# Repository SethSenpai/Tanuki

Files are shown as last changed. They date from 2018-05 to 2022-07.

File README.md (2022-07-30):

# Tanuki 40% keyboard
### The trash panda 40%

Tanuki

#### What is the Tanuki?
The Tanuki is a 40% keyboard that uses a split spacebar design to comfortably switch between layers. The design goal for the Tanuki was to make a staggered 40% keyboard out of materials I had lying around in my workshop.
This is also where it gets its name. A Tanuki or [Japanese raccoon dog](https://en.wikipedia.org/wiki/Japanese_raccoon_dog) is also known as a trash panda on the internet, which I felt was a fitting name for something build out of leftover materials.

#### Why open source?
The reason I am not doing a group buy or anything else of the sort is because I want people to experiment. To try different things with a keyboard that is not going to ruin your bank account if you get it wrong the first time.
I feel that running a group buy or outright producing this keyboard will take away the experimental nature of the project. I want people to take what I designed and mold it into something that is theirs. To use this more as a platform of departure rather than a guide to follow. Ok, I will stop rambling about design philosophy now.

You are of course more than welcome to run your own group buy!
**If you intend to use this design for commercial use, please go right ahead!**

#### Features
+ A staggered design.
+ Extremely small bezel.
+ Interactive RGB underglow that shows what layer you're on.
+ Buttons to turn off or reconfigure your underglow.
+ The ability to modify and adapt the keyboard to your wildest dreams! (and perhaps learn new skills doing so!)

#### How do I use the Tanuki?
The Tanuki works by having a split spacebar design. Holding either side of the spacebar will shift the keyboard to a different layer giving you access to the characters on that layer. 
Please note that while playing video games you should switch to the game layer. Some games to not handle the spacebar hold interaction well and will eat your inputs. (not good when playing your high adrenaline games)
Switching to the game layer will remove the hold function from the spacebar, fixing the problem.

#### Where is %this_key% on the keyboard?
The Tanuki has 3 layers, if the key you want is not on any of these layers you will have to dive into the firmware and put it somewhere you like!

**Base layer:**

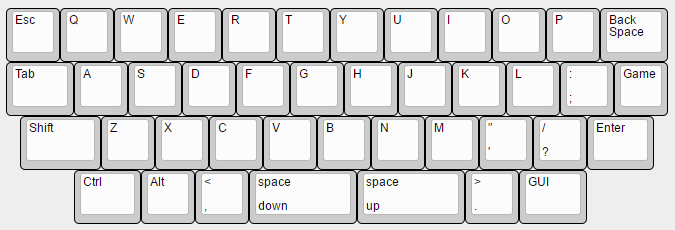
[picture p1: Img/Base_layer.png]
base


**Up layer:**

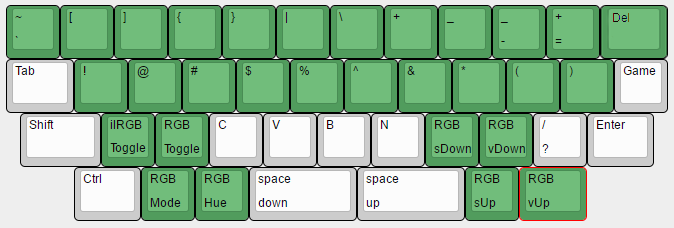
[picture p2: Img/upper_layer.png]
up


**Down layer:**

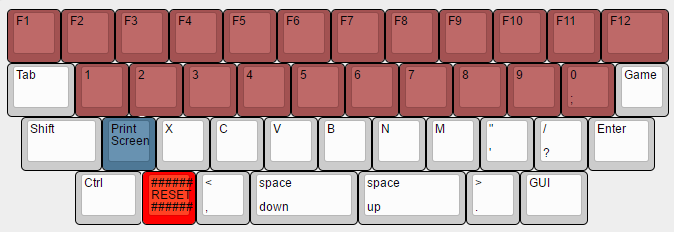
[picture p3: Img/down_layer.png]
down


**Game layer: (sort of a bad name I know more like arrow layer ah well)**

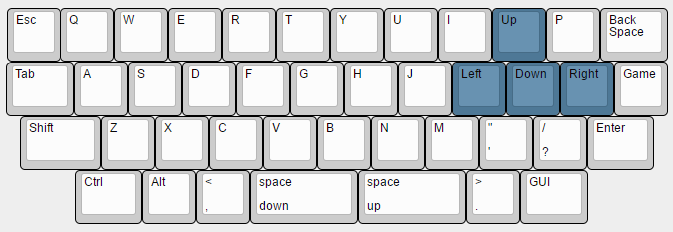
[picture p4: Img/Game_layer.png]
game


#### I'm sold, where do I go from here?
Visit the `Assembly and Parts` folder to get an idea of how to construct a Tanuki. Otherwise start by making a case by going to the `Case` folder. From there you can decide to handwire your Tanuki or have a pcb made. After that comes assembly and firmware! 

#### More pictures please?
glam2
glam3
glam4

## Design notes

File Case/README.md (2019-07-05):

# Tanuki 40% keyboard
### Case files

These are the case files for the Tanuki. There is a choice between 3d printing and lasercutting a sandwich case. Both have their own advantages and disadvantages. Notably for 3d printing is the time needed for printing the parts and the time investment to make it pretty afterwards. For lasercutting its the amount of paintwork that needs to be done and the relative annoying way of assembly.

### 3D Printing
The 3d printing files are split up into 5 files. Don't freak out most of them can be ignored based on your preferences and 3d printer. The full keyboard case doesn't fit on my Anet A6 and when I look around at the bed sizes for most 3d printers it likely won't fit on yours either. This is why the keyboard is split into 2 pieces.

*In case you have a big 3d printer*
+ TanukiCase.stl
+ TanukiCase_nologo.stl

*In case you have a 3d printer with a "average" size printbed*
+ TanukiCase_left.stl
+ TanukiCase_right.stl
+ TanukiCase_right_nologo.stl

The ..._nologo files are there because they have no indented logo on their front face. With 3d printed parts being more porous than smooth acrylic it is near impossible to scrape the paint off the front without paint streaks. I ended up filling it in with a very thin needle and the end result is well... ok enough? It is nowhere perfect so I decided to include files without the logo so you have a choice. Maybe a sticker is a better way to go...

*Print settings*

These vary from printer to printer, don't expect the first attempt to come out perfect.

+ layer height: 0.2mm
+ wall thickness: 1.2mm
+ infill density: 30%
+ infill pattern: lines
+ no support needed

You may need to rotate the model so the front of the case is laying down on the bed of the printer.

*Print aftercare*

Make sure to sand the inside of the mating surfaces of your print before attempting to glue it together. Glueing the parts together works really well with some low viscosity CA glue.

*What about the bottom of the case?*

Currently I just mount a lasercut 3mm clear acrylic part on the bottom with some 3mm bolts. However in the future I might design some nice 3d printed part that lets the light through nicely.

### Lasercutting
The Tanuki is designed to be laser cut out of 3mm acrylic but you are welcome to experiment. Please keep in mind the height needed for the components.
+ BLACK is a raster engraving.
+ BLUE should be the first lines to get cut.
+ CYAN should be the second lines to get cut.

If your local lasercut shop uses the colours differently please adjust them according to their specifications.

The strange circles and rectangles are there to be used as standoffs or as a way to hold the micro controller in place in case you're doing a handwired build.

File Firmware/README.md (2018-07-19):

# Tanuki 40% keyboard
### [Firmware files](https://github.com/qmk/qmk_firmware/tree/master/keyboards/tanuki)

#### Why are these files here?
The firmware files are also hosted over at [QMK](https://github.com/qmk/qmk_firmware/tree/master/keyboards/tanuki) and should be used to compile the firmware in a way that you like. These files are posted here to consolidate the files in one place and allow people to compile using older versions of QMK.

#### What do I do with this?
If this is your first time compiling keyboard firmware you might want to check out the [QMK guide](https://docs.qmk.fm/) or if you made no changes just [flash the .hex file to your pro micro](https://docs.qmk.fm/#/flashing).

#### Some notes on this firmware
This firmware release is for the PCB version only.

40% keyboard designed by Seth-Senpai. This repo is meant for the pcb version of the Tanuki. If you made any modifications to the board please make sure that the firmware reflects these changes.

If you decide to handwire a Tanuki just make sure to change the files correctly. If you're lost you can check out the [QMK hand wiring guide](https://docs.qmk.fm/#/hand_wire). The matrix is displayed below.

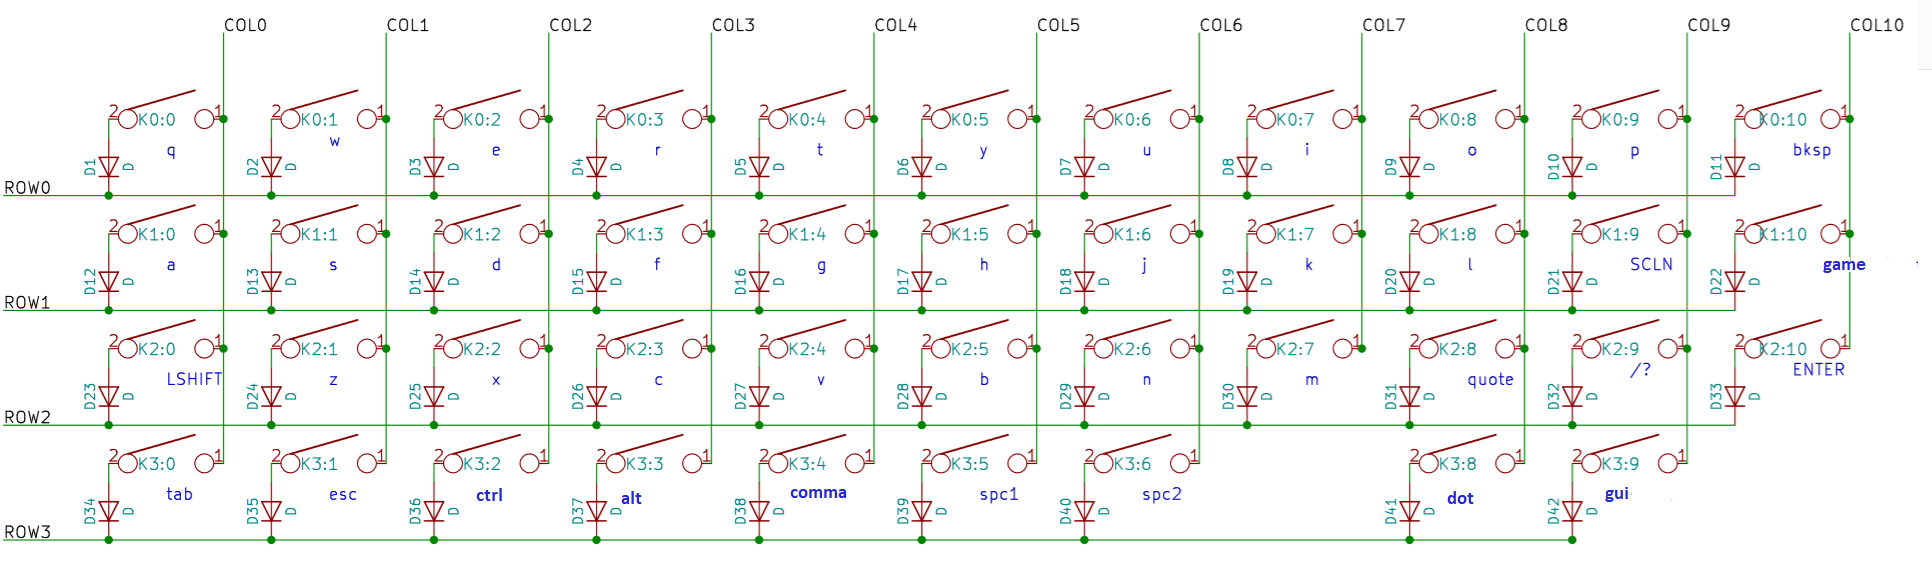
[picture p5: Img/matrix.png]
matrix


The pcb version uses a Pro Micro (atmel 32u4 based) controller.

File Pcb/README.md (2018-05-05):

# Tanuki 40% keyboard
### PCB files

#### What do I do with this?
+ If you just want to have a pcb made. Use the `Tanuki-gerber.zip` file and upload this to your pcb manufacturer of choice.
+ The files in the `Tanuki-gerber-files` folder mirror the files in the zip and this folder can be used to check if all the files that your manufacturer needs are there.
+ Otherwise modifications or new gerber files can be made by using the files found in the `Kicad files` folder.

Special thanks to [StormPegy](https://github.com/Stormpegy) for making the pcb.

#### Picture of a manufactured pcb
tanuki pcb

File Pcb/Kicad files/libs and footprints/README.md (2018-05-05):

# Tanuki 40% keyboard
### libraries and footprints

All rights to the respective owners of these libraries.

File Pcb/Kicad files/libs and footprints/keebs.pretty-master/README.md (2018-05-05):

# keebs.pretty

A KiCAD library for hybrid Cherry MX and Alps footprints that supports PCB mounted Cherry stabilizers. This is a revision of files found in [kiibohd/pcb](https://github.com/kiibohd/pcb) and [stormbard/Keyboard.pretty](https://github.com/stormbard/Keyboard.pretty)

Checkout [this tutorial](http://www.accelerated-designs.com/help/KiCad_Library.html)
if you are unfamiliar with importing KiCAD libraries.

If you come across any issues please don't hesitate to report them. Contributions are encouraged!

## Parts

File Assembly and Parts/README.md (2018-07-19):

# Tanuki 40% keyboard
### Materials and Assembly

These are not instructions. Keep in mind that you can change anything you like if you think it will work!

#### Part list pcb
|quantity  | description |
|---|---|
| x42 | diode smd: SOD-123 / SOD-80 (1N4148W / LL4148) or diode tht: DO-35 (1N4148 or similar) |
| x42 | MX style switches |
| x1 | resistor: 0603 500ohm |
| x1 | usb port: molex 54819-0519 |
| x1 | controller: arduino pro micro + headers |
| x5 | underglow led: WS2812B, this can also be a neopixel strip with 5 leds. |
| x1 | reset button: 3x6x2.5mm push button |
| x2 | stabilizer: costar style 2 unit (optional)|
| x1 | usb pigtail: cheap generic microusb cable to cut |

#### Part list case
|quantity  | description |
|---|---|
| x6 | 3M hexagonal nut. 2.4mm height. |
| x6 | 3M bolt. either 16 or 18 mm depending on the thickness of the board. |

#### Keycaps
I recommend using a DSA profile keycap but you can do anything you like. Freestyle man!

|quantity  | description |
|---|---|
| x34 | 1U keycap |
| x2 | 2U keycap |
| x5 | 1.25U keycap |
| x1 | 1.5U keycap |

#### Case parts preparation before assembly

If you want you can paint the upper parts of the keyboard so the underglow only shines through the bottom plate. When picking your spray-paint make sure that the propellant doesn't eat away at the plastic. Some of the propellants can be corrosive.

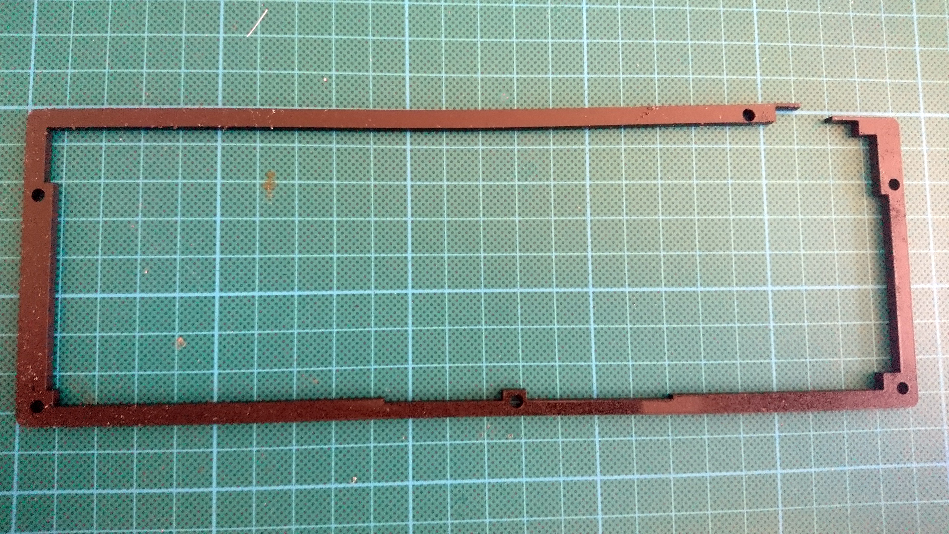
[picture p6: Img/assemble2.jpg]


The engraving on the front of the plate can be painted after by hand or filled by paint and then scraped off and cleaned off later with some isopropanol.

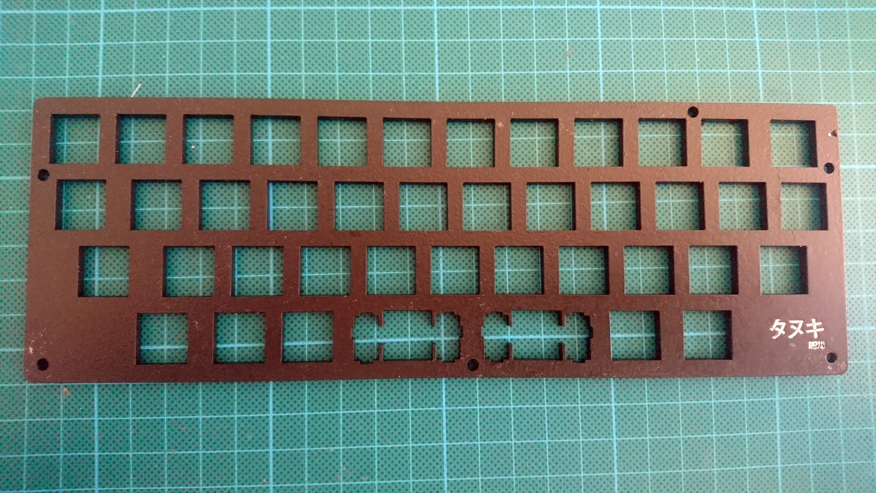
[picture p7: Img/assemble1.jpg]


If you want you can countersink the holes in top of the plate so the screws will fit on nice and flush later on.

The backplate can be sanded to increase the diffusion of the underglow through the side of the backplate. This makes the glow effect more spread and less like a flashlight.
In order to fit the backplate to the rest of the keyboard you should install some 3mm nuts in the slots on the backplate. You can glue them in place using superglue or epoxy.

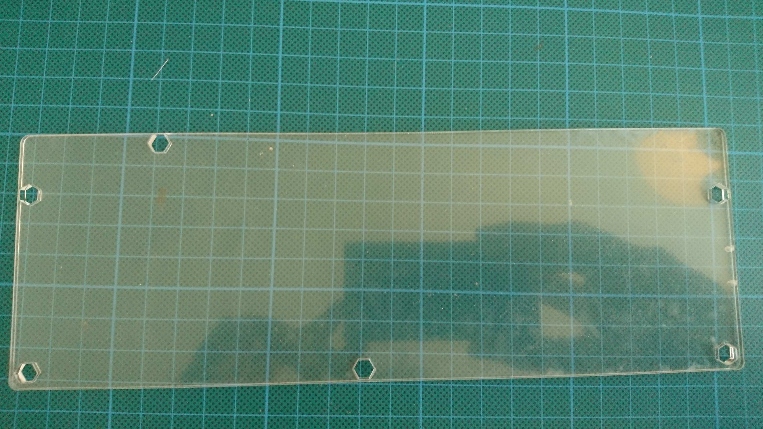
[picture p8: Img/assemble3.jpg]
sanding


When you're done it should look something like this: (except it won't be assembled yet)

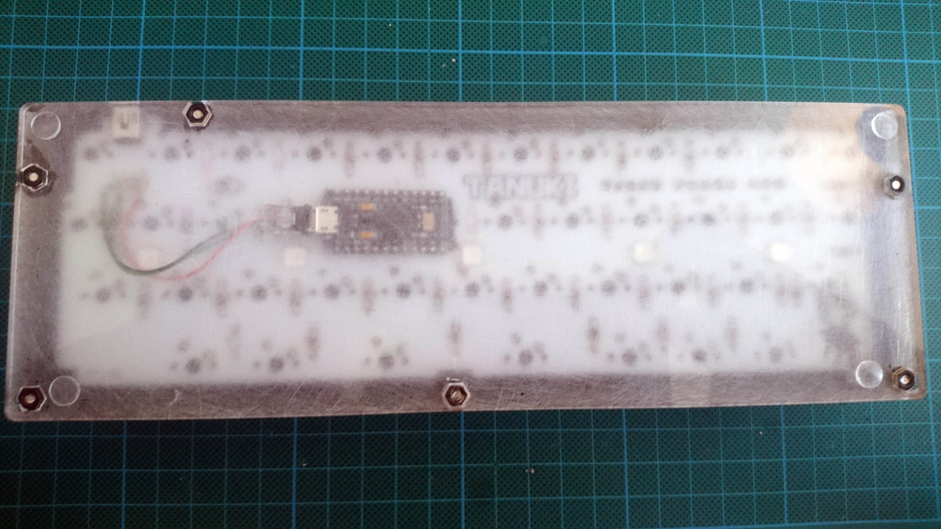
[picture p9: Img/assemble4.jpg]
assembled


#### Hand wiring

If you decide to handwire a Tanuki just make sure to change the files correctly. If you're lost you can check out the [QMK hand wiring guide](https://docs.qmk.fm/#/hand_wire). The matrix is displayed below.

matrix

#### PCB assembly

First part to solder to your pcb is the reset switch (if you have one) and the resistor for the led data line. ([this is not needed but **highly** recommended,](https://electronics.stackexchange.com/questions/102050/what-is-the-purpose-of-adding-a-300-ohm-to-500-ohm-resistor-on-the-ws2812b-neopi) in that case just bridge the pads).

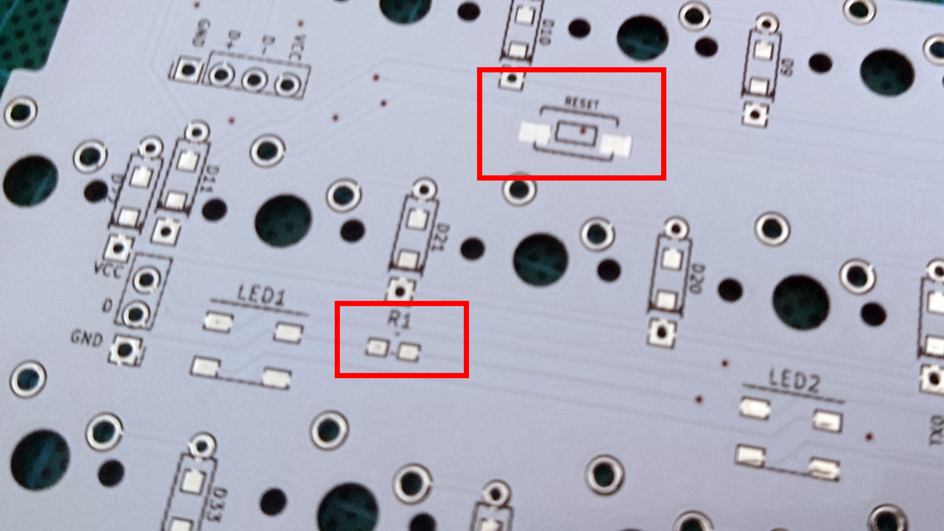
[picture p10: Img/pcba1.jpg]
ass1


The next step is to put all the diodes on the pcb. Make sure that the cathode (generally indicated by a mark on the diode) is pointing towards the square pad on the pcb.
If you're using through hole diodes it might be a good idea to put some diodes on the other side of the pcb. This makes sure that there is a nice spacer between the plate and the pcb and keeps the switches in place nicely.

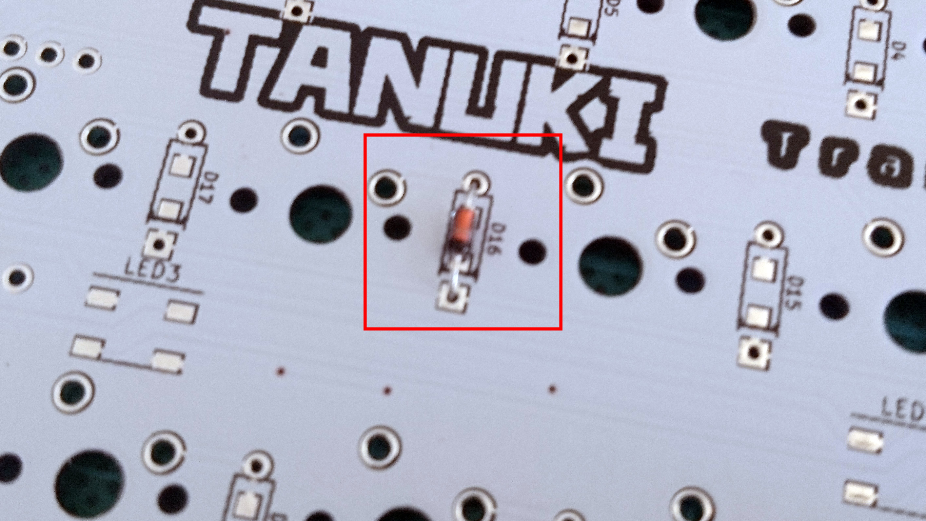
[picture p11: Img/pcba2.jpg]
ass2


Following this it is time to mount the leds on the pcb. When using the smd WS2812B leds make sure that the indent on one of the corners (the red circle in the picture) is pointing to the bottom right of the pcb.
Also keep in mind that the WS2812B leds are pretty heat sensitive so don't cook them!
If you want to hook up a neopixel strip just attach the wires to the appropriate breakout left of the first led.

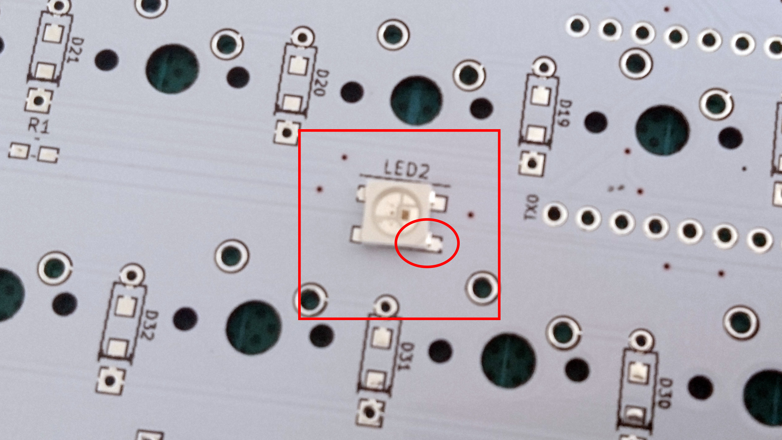
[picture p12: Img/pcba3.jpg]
ass3


Solder the usb chassis to the board. Make sure it is nice and straight.

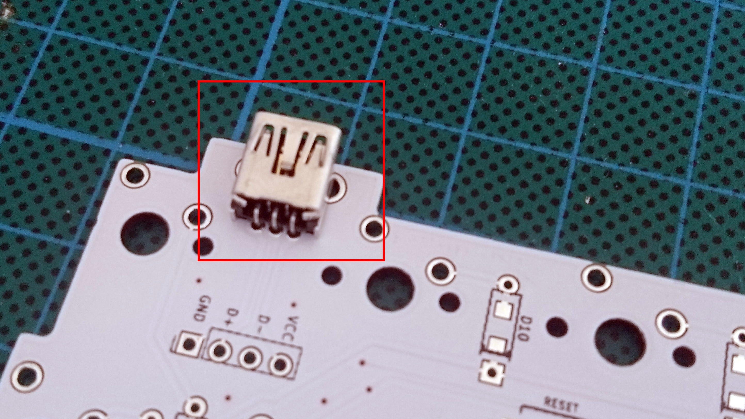
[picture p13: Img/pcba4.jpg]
ass4


Next are the headers for the pro micro. If you want to make the board slightly less thick you can remove the black standoffs in the header and just solder in the pins themselves. With a bit of dielectric tape on the back of the pro micro this can save you 2 to 3mm of height.

ass5

The next steps are to put the switches into the front plate and solder them to the board. I always mount the 4 corner switches first and then solder in the rest of the switches.
After this solder in the cut up micro usb cable to the breakout points on the board. It is generally helpful to remove the entire rubber outer layer of the cable to make it easier to solder and save on height space.

ass7

The last step is to solder in the pro micro. Make sure the tx0 port on the pro micro aligns with the indicator on the pcb. Plug in the micro usb chassis into the pro micro and the final assembled product looks something like this. Time to upload the [firmware](https://github.com/SethSenpai/Tanuki/tree/master/Firmware) and try it out.

ass6

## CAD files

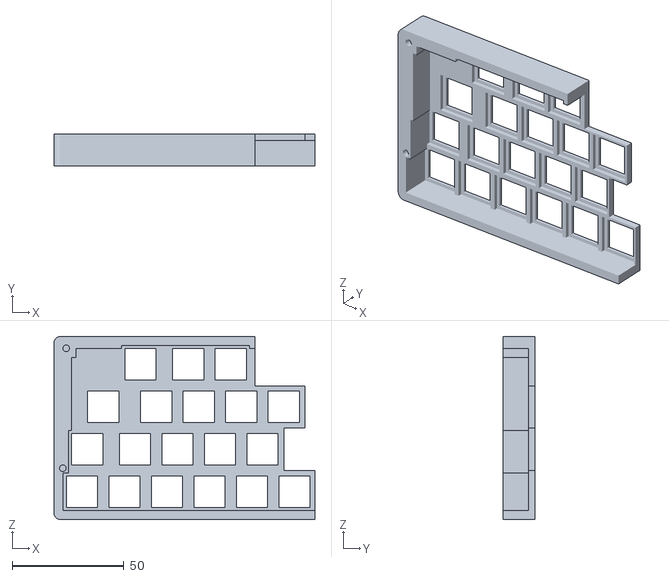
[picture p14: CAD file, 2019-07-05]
Case/3D_Printing/TanukiCase_left.stl
117.0 x 14.4 x 82.2

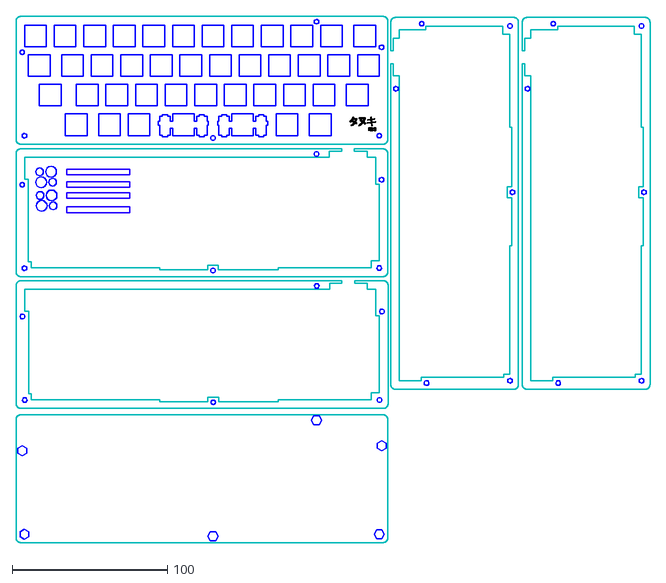
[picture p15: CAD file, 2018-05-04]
Case/Lasercut/tanuki_case_3mm.dxf
408.1 x 338.7

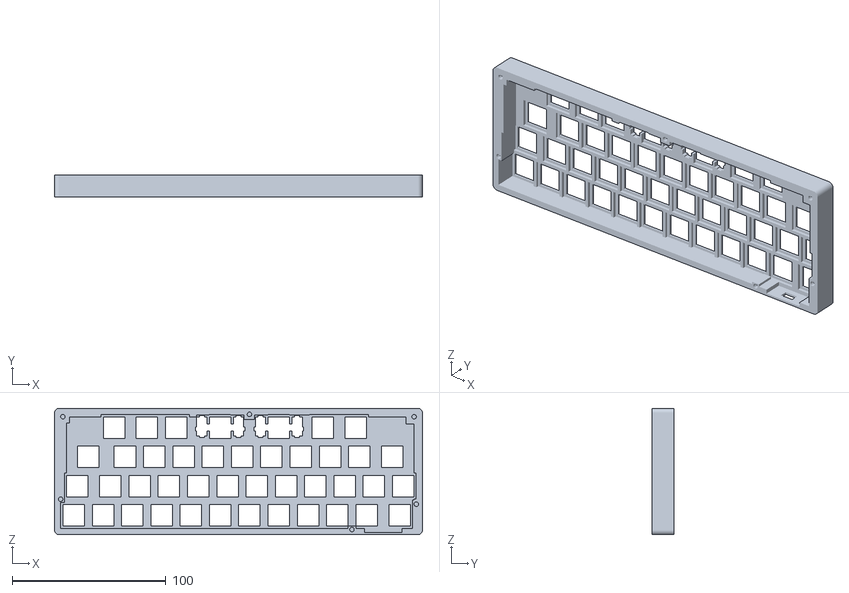
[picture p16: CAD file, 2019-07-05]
Case/3D_Printing/TanukiCase.stl
239.4 x 14.4 x 82.2

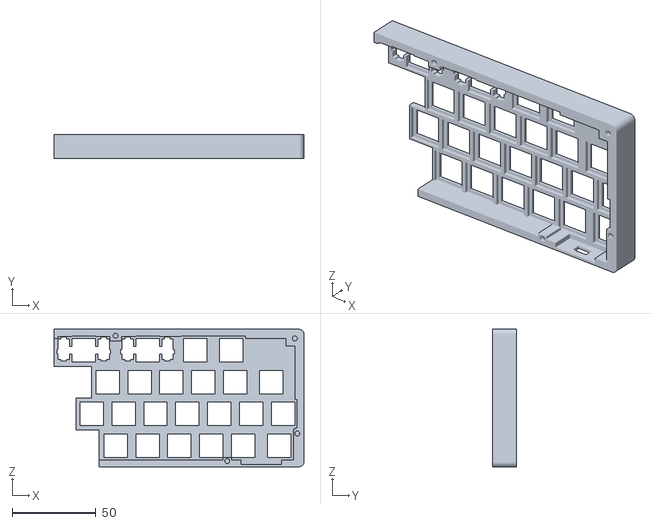
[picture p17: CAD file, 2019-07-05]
Case/3D_Printing/TanukiCase_right.stl
149.4 x 14.4 x 82.2

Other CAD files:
Case/3D_Printing/TanukiCase_nologo.stl
Case/3D_Printing/TanukiCase_right_nologo.stl

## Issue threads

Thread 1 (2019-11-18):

Request for another format of PCB design file

ohchiko, 2019-11-18:
Hey, I think it would be good if you can provide another format of the pcb design. The problem currently I have is there's no pcb printing service in my country that can use the gerber or the kicad. They use pdf, protel, altium, and eagle (but mostly use pdf).

And I know I can order using the gerber by the jlcpcb, but the shipping is too expensive (using dhl is 3 times of the board price). So I'd rather use the pcb printing service in my country instead.

I hope you can provide at least one of them.

Thanks!

SethSenpai, 2019-11-19:
I added a pdf version of the pcb files in the latest commit #e18efab. Got to admit never worked with a company that doesn't accept gerber but I guess its fair with it being a 20 year old standard almost. 😄

Closed 2019-11-19.

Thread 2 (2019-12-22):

RGB modes not working

ohchiko, 2019-12-22:
Going to "Up Layer" and pressing the "RGB Mode" or "RGB Hue" or "RGB sUp" or "RGB vUp" do nothing.
I was downloading the .hex file from the qmk toolbox, another buttons work well.

ohchiko, 2019-12-22:
resetting and reflash make this works. closing.

Closed 2019-12-22.

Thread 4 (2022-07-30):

about design

n1rdeks, 2022-07-30:
Amazing keyboard. Really. After using HHKB - the best choice. But, I have questions:

Firstly - staggered, maybe better ortho?
Secondly - need split this keyboard or not?

and latest question - really need any highlights :) ?

SethSenpai, 2022-07-30:
Hey,
Thanks for the praise!

You're more than welcome to create a ortho and split version of the Tanuki, I personally don't like typing on ortho because I'm an old man but you're welcome to Fork the project and remix it.

I'm a bit confused what you mean with highlights?

n1rdeks, 2022-07-30:
> what you mean with highlights?

For touch-typing not needed any LEDs, IMO. I prefer Improved Dvorak... This is fixed xkb (in Linux) for keyboards, who did not have any QMK:

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

Do you think staggered better for typing? And what u think about this format? - https://github.com/foostan/crkbd

And last question. I very, very like Topre switches. Maybe possible create this keyboard with Topre switches?

P.S. Sorry for my English...

SethSenpai, 2022-07-30:
> For touch-typing not needed any LEDs, IMO.

Ah alright, I put the LED's in to give a visual confirmation of the layer that you're on with your keyboard. I feel it's quite nice but you can just leave them out if you don't want them.

> Do you think staggered better for typing?

Depends on what you're used to. I learned typing on an ancient mechanical typewriter so staggered qwerty is just all I've known.

> And what u think about this format?

Looks nice! I do a lot of CAD work so personally I think I'd like something that has the modifier keys easier to access without having your hands in typing mode.

> Maybe possible create this keyboard with Topre switches?

Yes this should totally work, _you_ will need to modify the pcb and plate a bunch. And need to find a place to source the topre "switches". Since they're so closely related to the layout of the pcb. Maybe a good place to start is to make a 4 key macropad with the topre switches first to get a handle on using them since they're quite a bit different from your standard switch.

> P.S. Sorry for my English...

No problem, you can only get better with practice!

n1rdeks, 2022-07-30:
>Maybe a good place to start is to make a 4 key macropad with the topre switches

Thanks for amazing advice. Well, need a practice...

Closed 2022-07-30.

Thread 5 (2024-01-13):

What can I do if I use the 3d printing case?

Mark-Miao, 2024-01-13:
There is a problem that we don't have any mount holes on the front of the model
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
So how can I mount the back?

SethSenpai, 2024-01-13:
Hey there, The idea is to use the holes on the back to mount a baseplate to the top of the device. This takes normal M3 bolts and should close up the device fully.

Mark-Miao, 2024-01-13:
Yep，I noticed that a few minutes later~

Closed 2024-01-13.

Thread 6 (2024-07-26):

Measurements of the lasercut file

liamkhoi, 2024-07-26:
Hi, I recently did a lasercut of this keyboard. However, I noticed that the file is actually saved in the wrong measurements.
Currently, the .dxf file properties are in inches and not in millimeters. When exporting, it will convert to a gigantic cutting area if your software reads the original measurements. I think the file should be resaved in the correct drawing preferences.

liamkhoi, 2025-05-30:
Hi, it's been a while without any responses,

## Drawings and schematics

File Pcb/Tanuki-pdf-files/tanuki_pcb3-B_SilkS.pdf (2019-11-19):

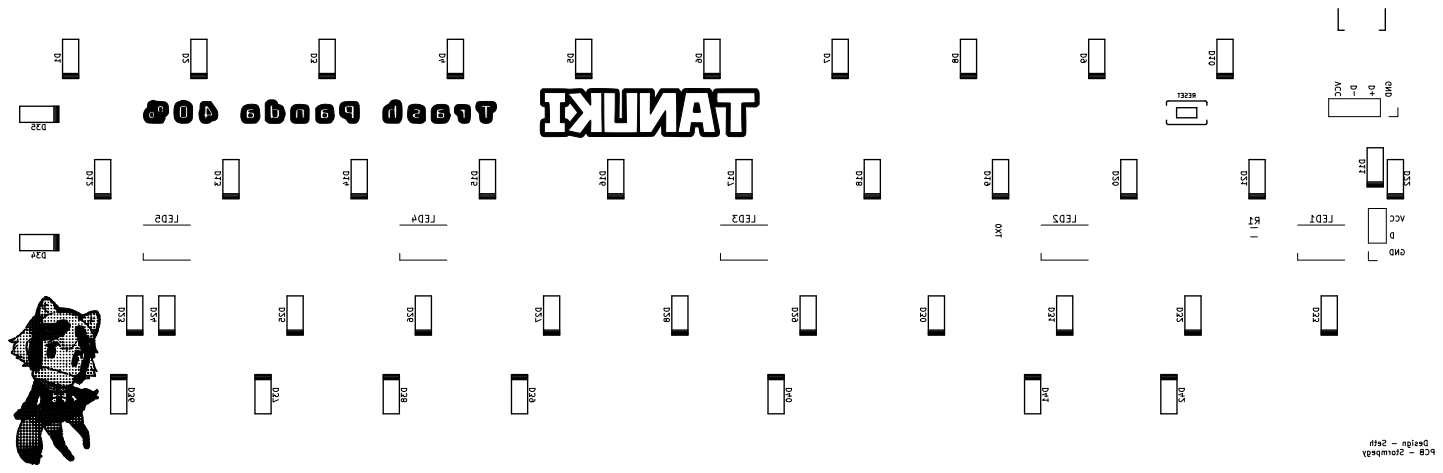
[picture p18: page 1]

Design - Seth PCB - Stormpegy GNDD- D+ GND TX0 D

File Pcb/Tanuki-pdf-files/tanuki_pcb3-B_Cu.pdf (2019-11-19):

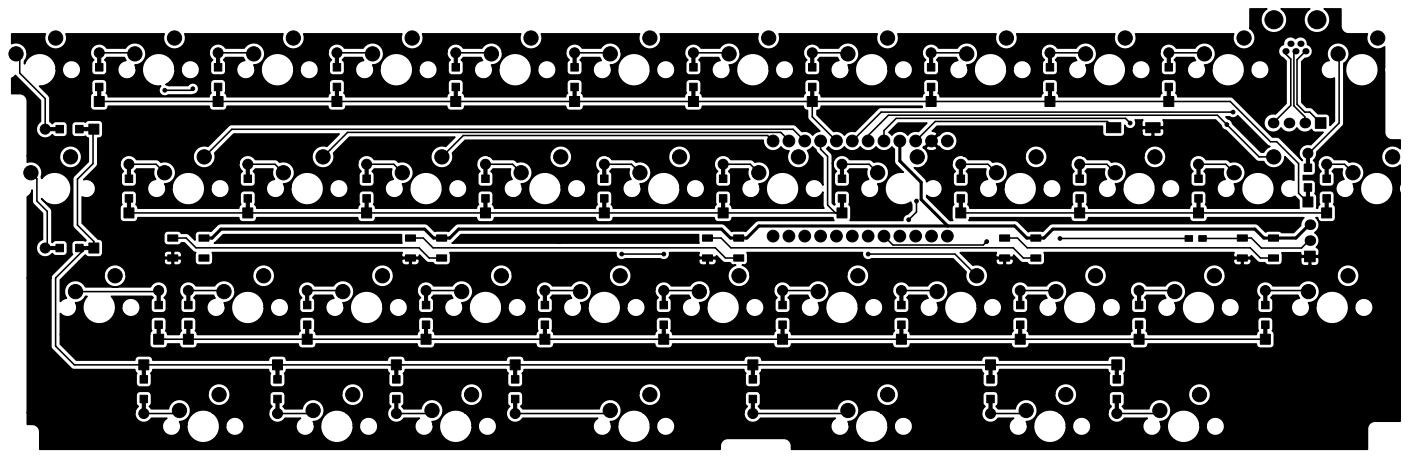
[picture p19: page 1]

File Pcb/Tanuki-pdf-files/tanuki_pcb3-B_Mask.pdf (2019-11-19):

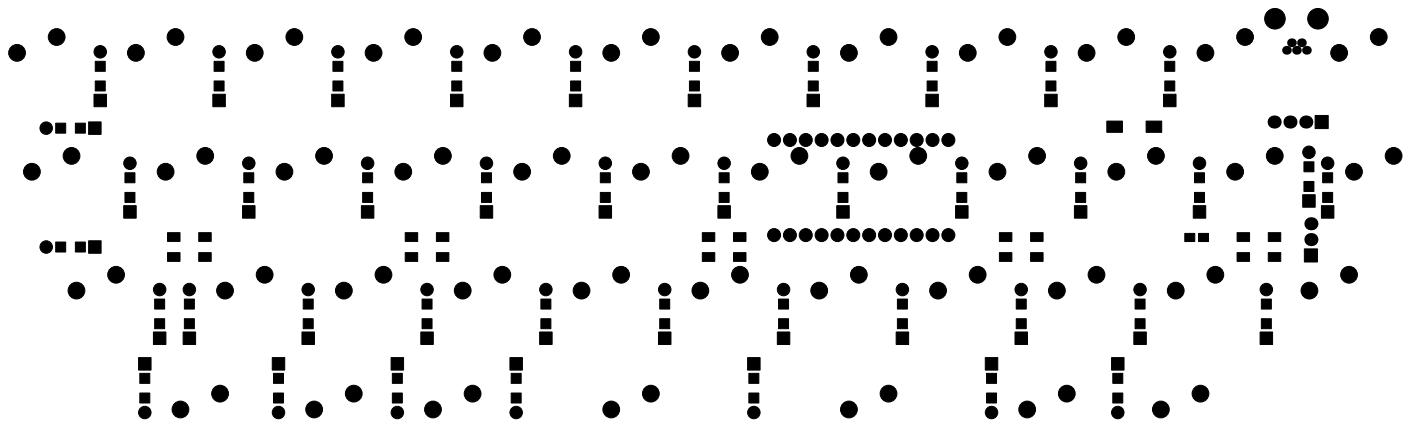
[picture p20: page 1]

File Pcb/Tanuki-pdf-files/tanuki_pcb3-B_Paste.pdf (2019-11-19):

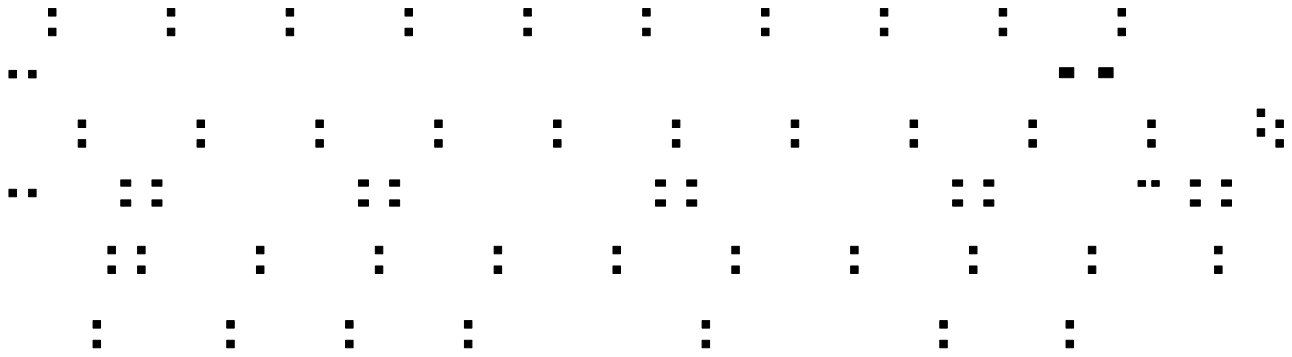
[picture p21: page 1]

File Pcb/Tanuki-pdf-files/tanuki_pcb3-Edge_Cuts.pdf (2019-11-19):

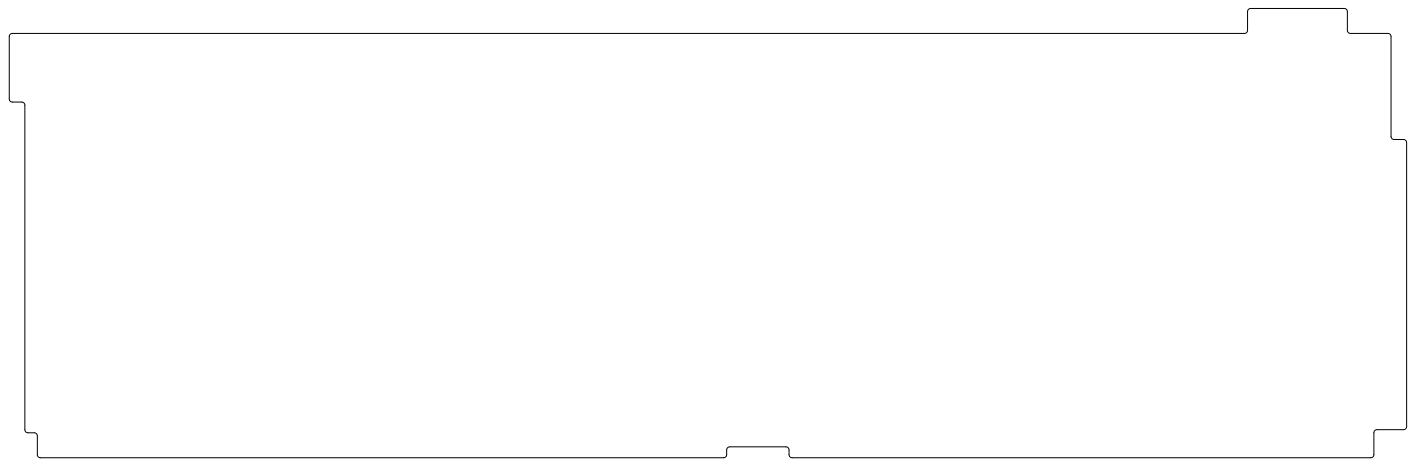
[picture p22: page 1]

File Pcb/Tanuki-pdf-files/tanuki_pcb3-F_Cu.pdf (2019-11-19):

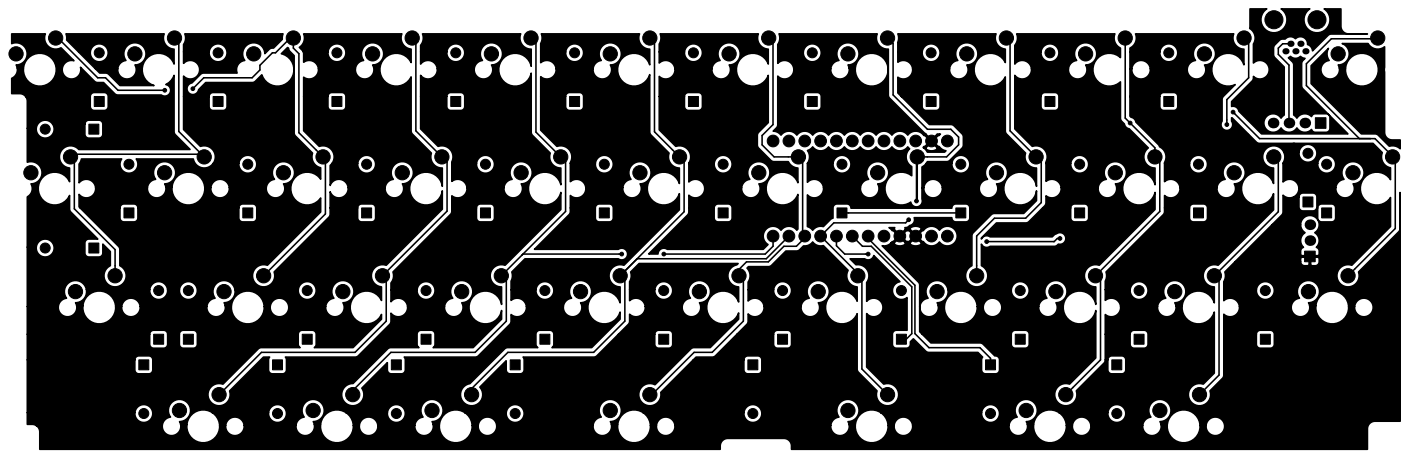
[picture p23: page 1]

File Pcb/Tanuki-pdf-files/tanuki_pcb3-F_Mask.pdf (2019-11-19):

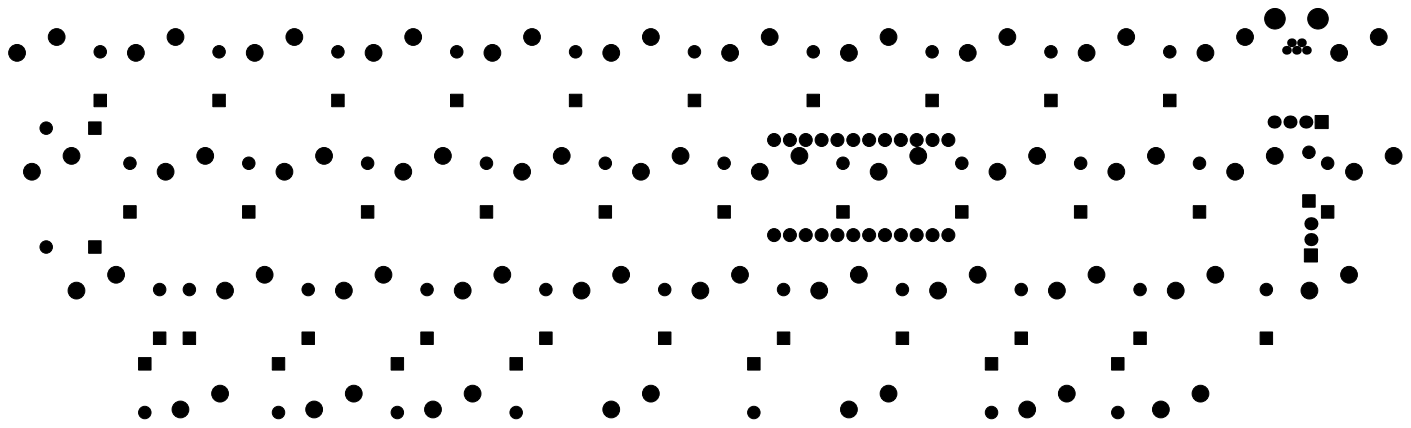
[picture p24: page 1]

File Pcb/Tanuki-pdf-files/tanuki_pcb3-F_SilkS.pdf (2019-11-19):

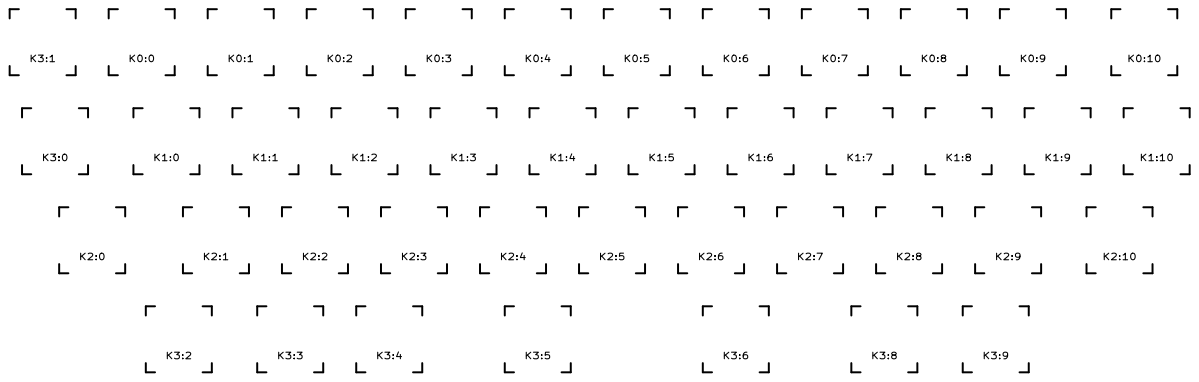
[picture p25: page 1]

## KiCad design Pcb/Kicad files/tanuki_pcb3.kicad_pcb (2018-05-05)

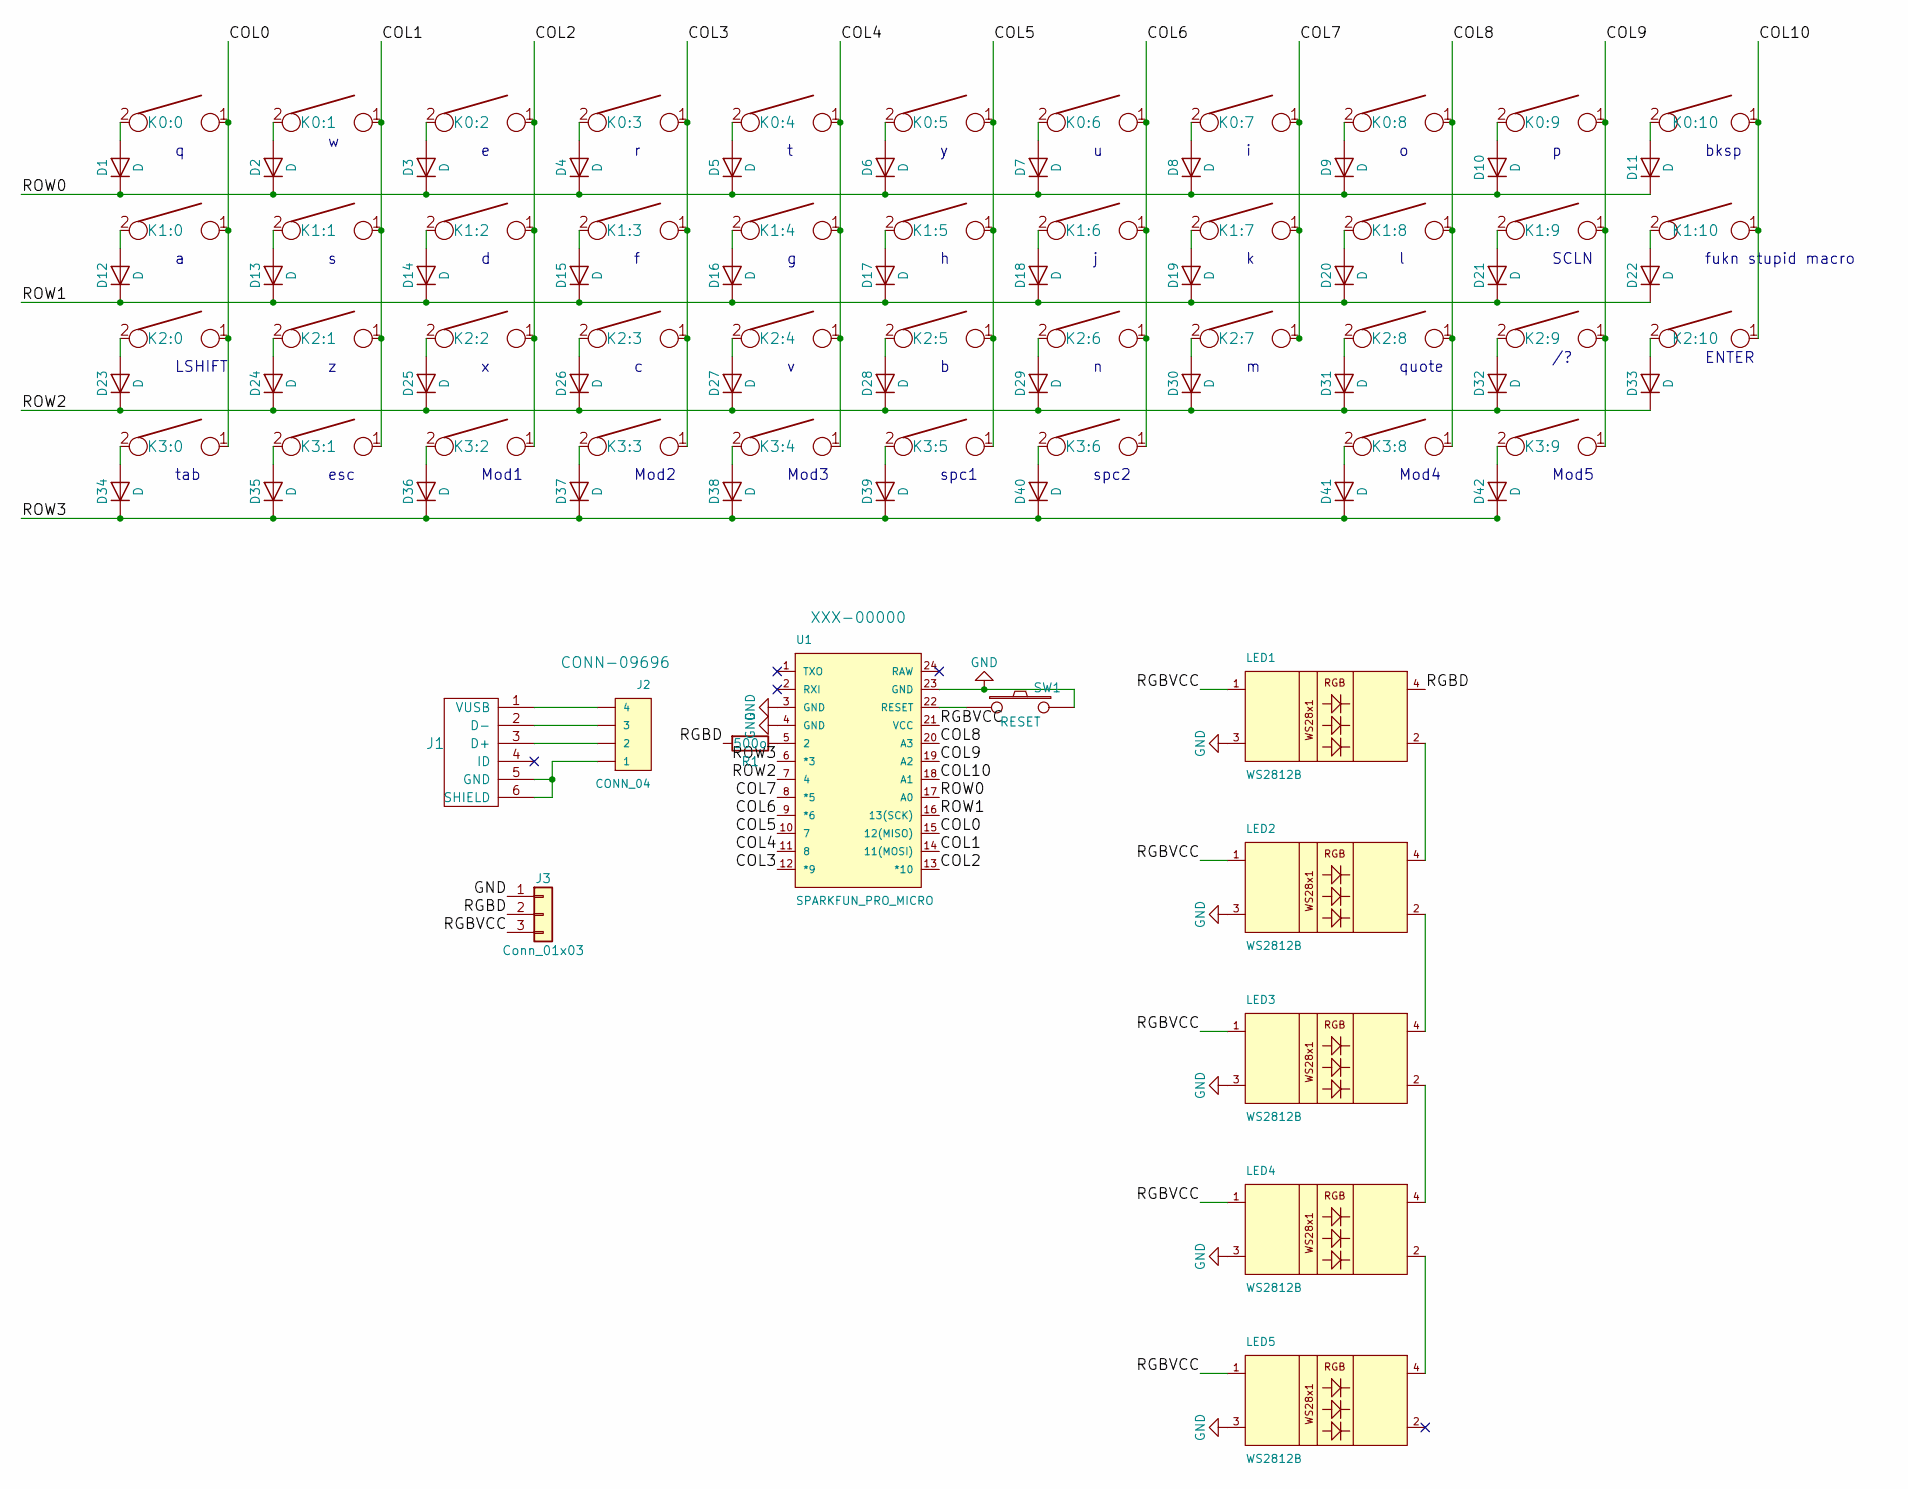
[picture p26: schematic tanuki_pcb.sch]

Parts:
D1, D2, D3, D4, D5, D6, D7, D8, D9, D10, D11, D12, D13, D14, D15, D16, D17, D18, D19, D20, D21, D22, D23, D24, D25, D26, D27, D28, D29, D30, D31, D32, D33, D34, D35, D36, D37, D38, D39, D40, D41, D42: D; D_SOD123_axial
J1: USB_mini_micro_B; 54819-0519fix2
J2: CONN_04; Pin_Header_Straight_1x04_Pitch2.54mm
J3: Conn_01x03; Pin_Header_Straight_1x03_Pitch2.54mm
K0:0, K0:1, K0:2, K0:3, K0:4, K0:5, K0:6, K0:7, K0:8, K0:9, K1:0, K1:1, K1:2, K1:3, K1:4, K1:5, K1:6, K1:7, K1:8, K1:9, K1:10, K2:1, K2:2, K2:3, K2:4, K2:5, K2:6, K2:7, K2:8, K2:9, K3:1, K3:3, K3:4, K3:5, K3:6, K3:8: KEYSW; MX_PCB_100H
K0:10, K2:10, K3:0, K3:2, K3:9: KEYSW; MX_PCB_125H
K2:0: KEYSW; MX_PCB_150H
LED1, LED2, LED3, LED4, LED5: WS2812B; LED_WS2812B-PLCC4
R1: 500o; R_0603_HandSoldering
SW1: RESET; TACTILE_SWITCH_SMD_6.0X3.5MM
U1: SPARKFUN_PRO_MICRO

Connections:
/COL0: K0:0.1, K1:0.1, K2:0.1, K3:0.1, U1.15 (12(MISO))
/COL1: K0:1.1, K1:1.1, K2:1.1, K3:1.1, U1.14 (11(MOSI))
/COL2: K0:2.1, K1:2.1, K2:2.1, K3:2.1, U1.13 (*10)
/COL3: K0:3.1, K1:3.1, K2:3.1, K3:3.1, U1.12 (*9)
/COL4: K0:4.1, K1:4.1, K2:4.1, K3:4.1, U1.11 (8)
/COL5: K0:5.1, K1:5.1, K2:5.1, K3:5.1, U1.10 (7)
/COL6: K0:6.1, K1:6.1, K2:6.1, K3:6.1, U1.9 (*6)
/COL7: K0:7.1, K1:7.1, K2:7.1, U1.8 (*5)
/COL8: K0:8.1, K1:8.1, K2:8.1, K3:8.1, U1.20 (A3)
/COL9: K0:9.1, K1:9.1, K2:9.1, K3:9.1, U1.19 (A2)
/COL10: K0:10.1, K1:10.1, K2:10.1, U1.18 (A1)
/RGBD: J3.2, LED1.4 (DI), R1.2
/RGBVCC: J3.3, LED1.1 (VDD), LED2.1 (VDD), LED3.1 (VDD), LED4.1 (VDD), LED5.1 (VDD), U1.21 (VCC)
/ROW0: D1.1 (K), D2.1 (K), D3.1 (K), D4.1 (K), D5.1 (K), D6.1 (K), D7.1 (K), D8.1 (K), D9.1 (K), D10.1 (K), D11.1 (K), U1.17 (A0)
/ROW1: D12.1 (K), D13.1 (K), D14.1 (K), D15.1 (K), D16.1 (K), D17.1 (K), D18.1 (K), D19.1 (K), D20.1 (K), D21.1 (K), D22.1 (K), U1.16 (13(SCK))
/ROW2: D23.1 (K), D24.1 (K), D25.1 (K), D26.1 (K), D27.1 (K), D28.1 (K), D29.1 (K), D30.1 (K), D31.1 (K), D32.1 (K), D33.1 (K), U1.7 (4)
/ROW3: D34.1 (K), D35.1 (K), D36.1 (K), D37.1 (K), D38.1 (K), D39.1 (K), D40.1 (K), D41.1 (K), D42.1 (K), U1.6 (*3)
GND: J3.1, LED1.3 (VSS), LED2.3 (VSS), LED3.3 (VSS), LED4.3 (VSS), LED5.3 (VSS), SW1.2, U1.3 (GND), U1.4 (GND), U1.23 (GND)
unnamed: D1.2 (A), K0:0.2
unnamed: D2.2 (A), K0:1.2
unnamed: D3.2 (A), K0:2.2
unnamed: D4.2 (A), K0:3.2
unnamed: D5.2 (A), K0:4.2
unnamed: D6.2 (A), K0:5.2
unnamed: D7.2 (A), K0:6.2
unnamed: D8.2 (A), K0:7.2
unnamed: D9.2 (A), K0:8.2
unnamed: D10.2 (A), K0:9.2
unnamed: D11.2 (A), K0:10.2
unnamed: D12.2 (A), K1:0.2
unnamed: D13.2 (A), K1:1.2
unnamed: D14.2 (A), K1:2.2
unnamed: D15.2 (A), K1:3.2
unnamed: D16.2 (A), K1:4.2
unnamed: D17.2 (A), K1:5.2
unnamed: D18.2 (A), K1:6.2
unnamed: D19.2 (A), K1:7.2
unnamed: D20.2 (A), K1:8.2
unnamed: D21.2 (A), K1:9.2
unnamed: D22.2 (A), K1:10.2
unnamed: D23.2 (A), K2:0.2
unnamed: D24.2 (A), K2:1.2
unnamed: D25.2 (A), K2:2.2
unnamed: D26.2 (A), K2:3.2
unnamed: D27.2 (A), K2:4.2
unnamed: D28.2 (A), K2:5.2
unnamed: D29.2 (A), K2:6.2
unnamed: D30.2 (A), K2:7.2
unnamed: D31.2 (A), K2:8.2
unnamed: D32.2 (A), K2:9.2
unnamed: D33.2 (A), K2:10.2
unnamed: D34.2 (A), K3:0.2
unnamed: D35.2 (A), K3:1.2
unnamed: D36.2 (A), K3:2.2
unnamed: D37.2 (A), K3:3.2
unnamed: D38.2 (A), K3:4.2
unnamed: D39.2 (A), K3:5.2
unnamed: D40.2 (A), K3:6.2
unnamed: D41.2 (A), K3:8.2
unnamed: D42.2 (A), K3:9.2
unnamed: J1.1 (VUSB), J2.4
unnamed: J1.2 (D-), J2.3
unnamed: J1.3 (D+), J2.2
unnamed: J1.5 (GND), J1.6 (SHIELD), J2.1
unnamed: LED1.2 (DO), LED2.4 (DI)
unnamed: LED2.2 (DO), LED3.4 (DI)
unnamed: LED3.2 (DO), LED4.4 (DI)
unnamed: LED4.2 (DO), LED5.4 (DI)
unnamed: R1.1, U1.5 (2)
unnamed: SW1.1, U1.22 (RESET)

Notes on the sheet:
tab
esc
Mod1
Mod2
Mod3
spc1
spc2
Mod4
Mod5
quote
LSHIFT
ENTER
SCLN
bksp
fukn stupid macro

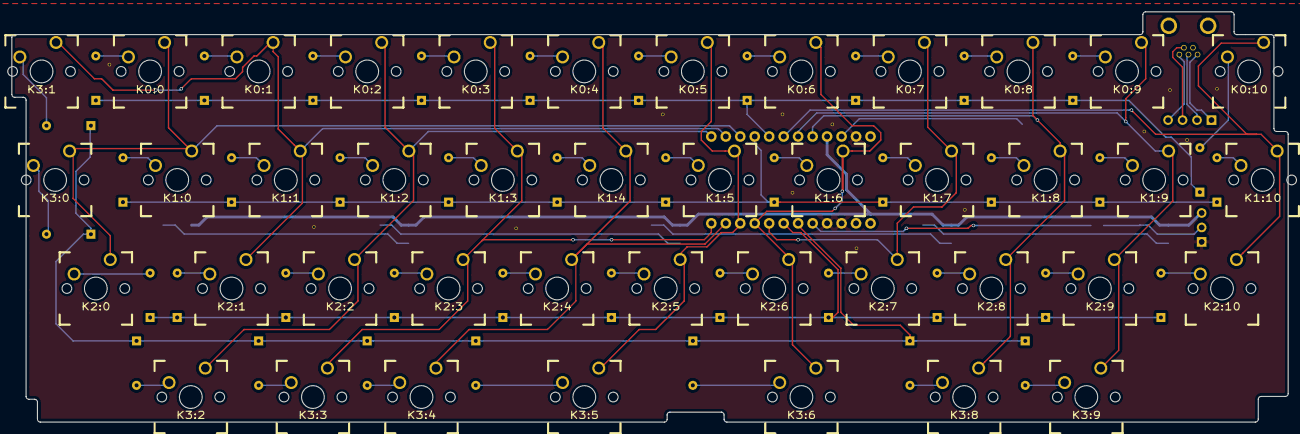
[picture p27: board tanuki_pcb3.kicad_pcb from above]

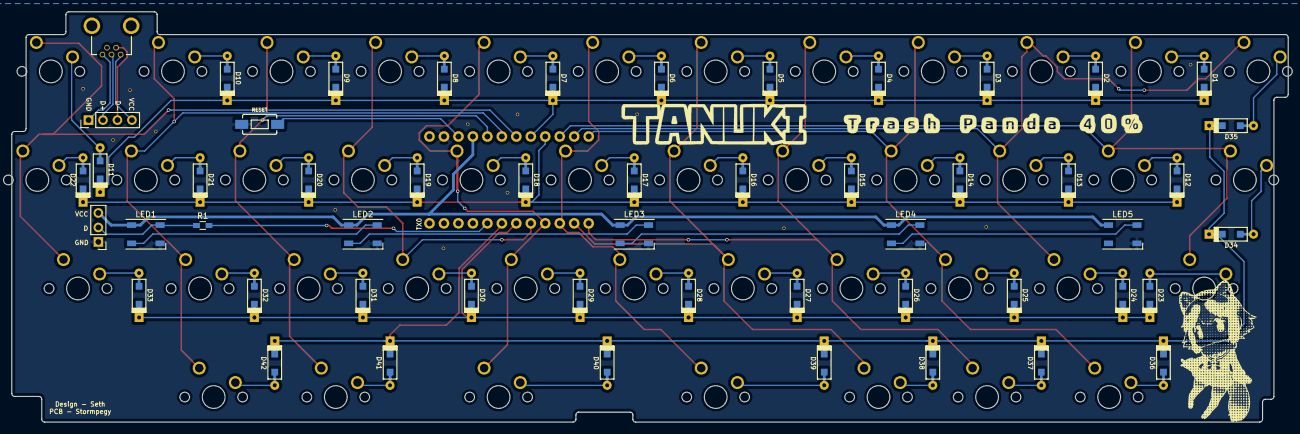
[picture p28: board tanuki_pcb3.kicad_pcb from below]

Board: 2 copper layers, 224.0 x 72.0 mm, 95 parts (53 on the bottom side), 70 nets.

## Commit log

2018-05-04 added readme for case folder
2018-05-05 added pcb files
    [tanuki_pcb.sch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]
2018-05-05 pcb stuff update
2018-05-05 picture for pcb readme
2018-05-05 update case and firmware readme
2018-05-05 added assembly and pcb pictures
2019-07-05 added 3d files for 3d printing, updated the case readme
    [TanukiCase.stl, TanukiCase_left.stl, TanukiCase_nologo.stl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]
2019-11-19 added pdf version of the pcb
    [tanuki_pcb3-NPTH.drl, tanuki_pcb3-PTH.drl]
